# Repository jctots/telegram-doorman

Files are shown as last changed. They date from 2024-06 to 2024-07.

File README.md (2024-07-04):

# 🚪 telegram-doorman
Interact with your [TCS](https://www.tcsag.de/) or [Koch](https://www.kochag.ch/de/) intercom with a Telegram Bot and ESP8266



<table border="0">
<tr><td>Open Door Demo<br></td>
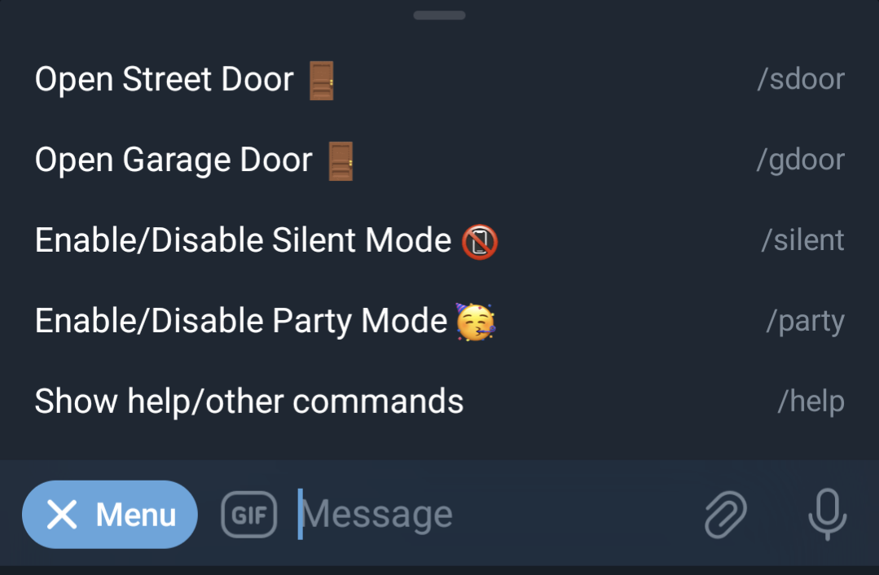
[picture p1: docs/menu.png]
    <td>Telegram Actions<br>
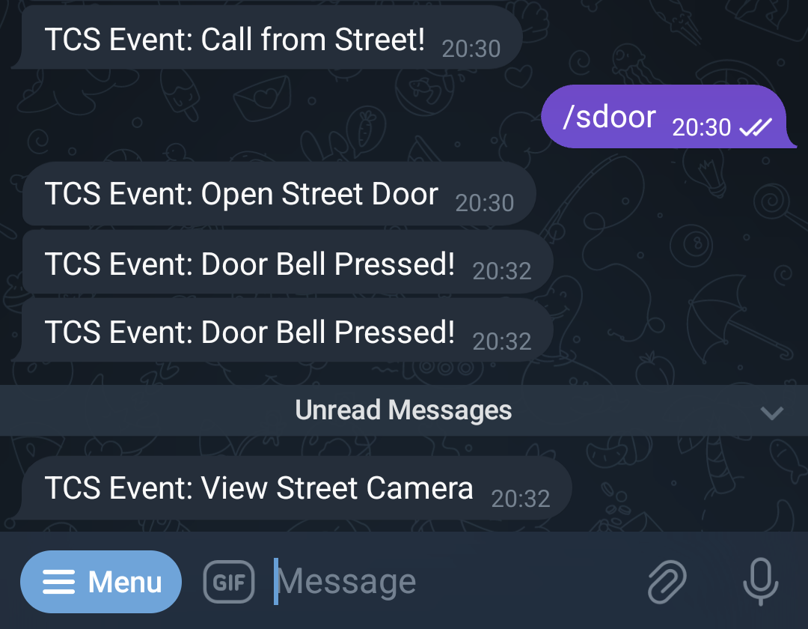
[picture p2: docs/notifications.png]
    <br><br>Example Notifications<br>
    </td>
</tr>
</table>

Currently supported TCS bus events:
- send open door command (up to two doors)
- receive notifications for open door
- receive notifications for intercom call
- receive notifications for apartment doorbell
- receive notifications during lift handset

# 📱 Features
- Multi-user: easily register/remove additional 2 telegram chatIDs (group chatID or user chatID) as bot user
- Silent mode (per user): disable notification of TCS bus events for specific user
- Party mode (all users): automatic door unlock every intercom call
- Sniff mode (main user): forward all TCS bus events (for collecting protocol codes for initial configuration) 
- Dev mode (main user): silent mode for other users and enable sniff mode (useful for debugging and testing)
- Simple DevOps environment via PlatformIO, Arduino OTA, and GitHub Actions

Other hardware-specific features:
- possible isolation of TCS BUS and ESP circuit via optocoupler when ESP is powered by separate supply 
- possible de-isolation of TCS BUS and ESP circuit via jumper when ESP is powered by TCS bus P-Line
- separate pin for resetting config to defaults (short-to-ground)

# ⚙️ System Overview
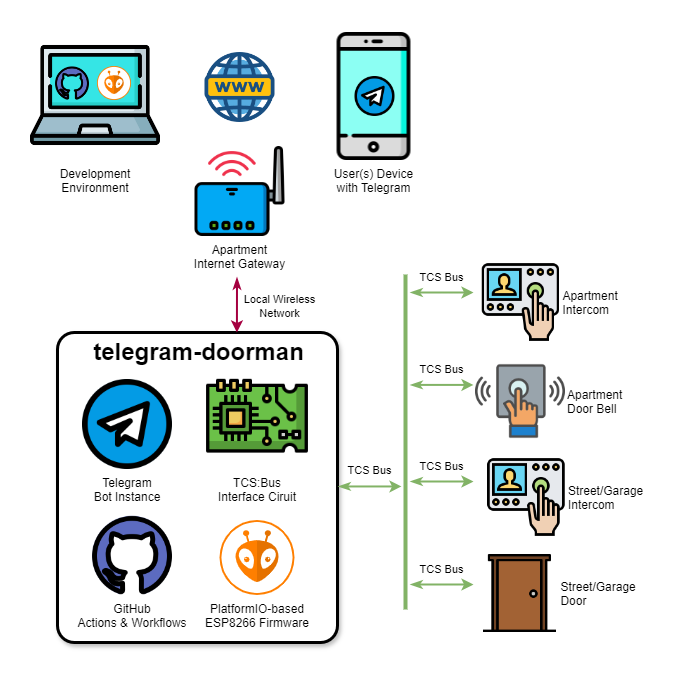
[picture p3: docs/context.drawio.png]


# 🚀 Getting Started
(Detailed user manual coming soon in /docs)
- Setup PlatformIO dev environment and build (or download latest .bin from release)
- Make interface circuit
- Setup Telegram Bot
- Flash, integrate and test
- Enable "Sniff Mode" to capture own TCS:Bus protocol codes
- Change default config with captured codes
- Enjoy!

# 🔧 Reference Circuit and Integration
(Detailed integration manual coming soon in /docs)
<table border="0">
  <tr>
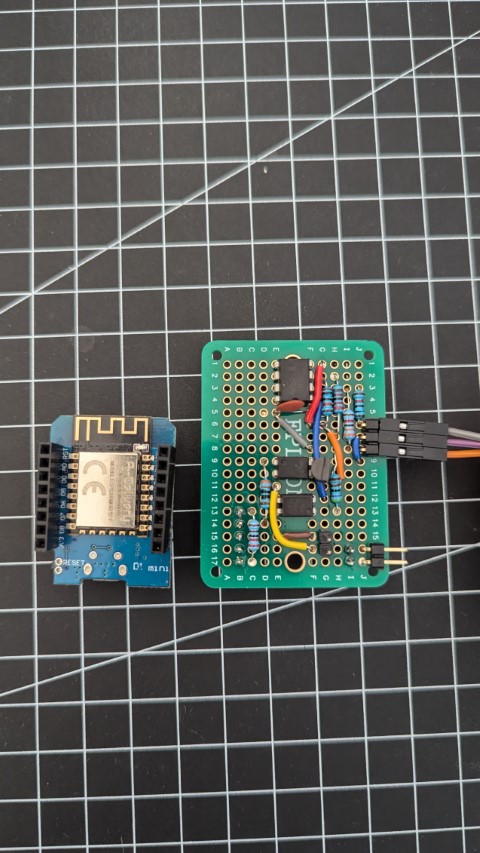
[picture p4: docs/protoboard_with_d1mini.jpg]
    <td></td>
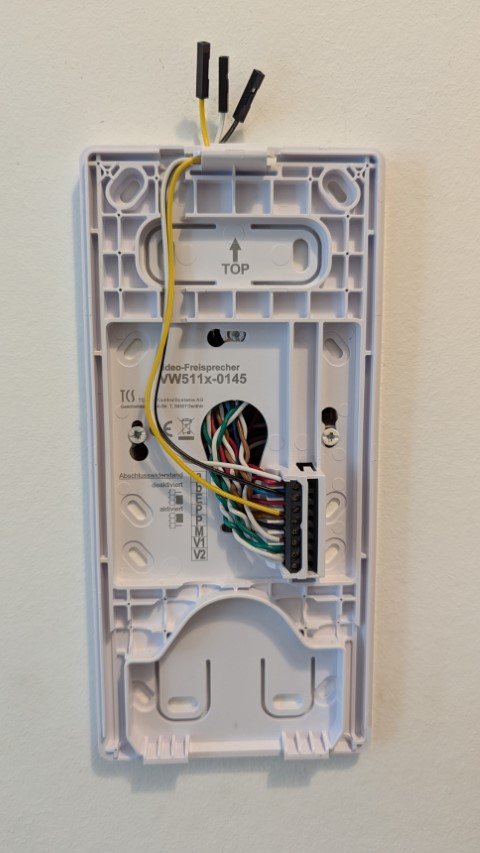
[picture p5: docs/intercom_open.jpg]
    <td></td>
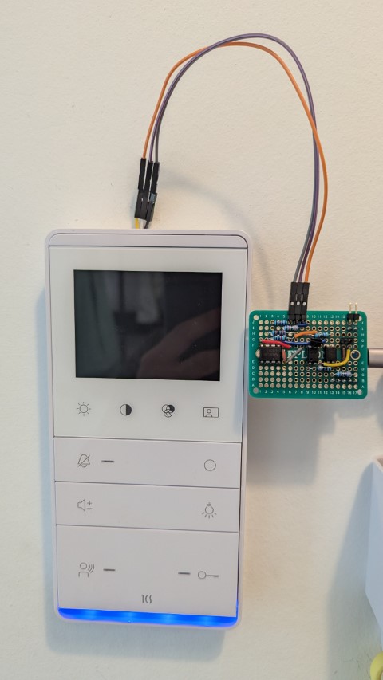
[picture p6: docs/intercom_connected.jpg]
    <td></td>
  </tr>
</table>

[Link to Interface Circuit Schematic Diagram](/docs/schematic.jpg)

# ✔️ To-do 
- [ ] find a way to power ESP from TCS bus P-Line without cracking sound
- [ ] proper cabling and housing
- [ ] support for [telegram-keyman](https://github.com/jctots/telegram-keyman) for complete keyless apartment entry!
- [ ] create user manual, getting started (sphinx-docs), integration manual (with oscilloscope photos)
- [ ] add section for known issues and limitations
- [ ] low power mode/wake-up/proper scheduling for optional battery support
- [ ] PCB layout
- [ ] logs (reset counter, etc.) and error handling
- [ ] simple HTML web server to update config
- [ ] simple web server for wireless serial debugging
- [ ] add sample unit tests for TDD demo
- [ ] create GitHub actions for automated test and docs generation
- [ ] add sample domain and application models for DDD demo

# 🗻 Challenges
- from the [TCS Hacking YouTube video](https://youtu.be/xFLoauqj9yA?si=zF_Vwu4iNptckhIR), the TCS Bus A-Line is between 20V-24V, our system is between 7V-24V (verified using oscilloscope)
- in our apartment, we have 2 doors: main door (facing street) and garage door (inside tiefgarage)
- our system has 6-line TCS bus with video intercom (instead of the usual 2/3 line)
    - getting 5V from the 24V TCS bus P-line using DC-DC buck converter to power the ESP produces noise (cracking sound) in the video intercom (EMI/grounding issues?)
    - decided to use an optocoupler to separate the ESP ground from the TCS bus B-line
 
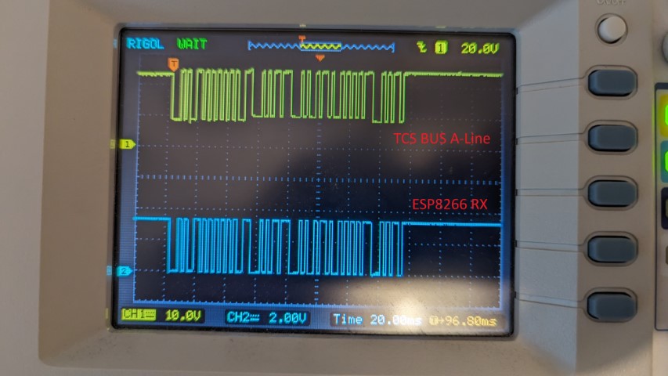
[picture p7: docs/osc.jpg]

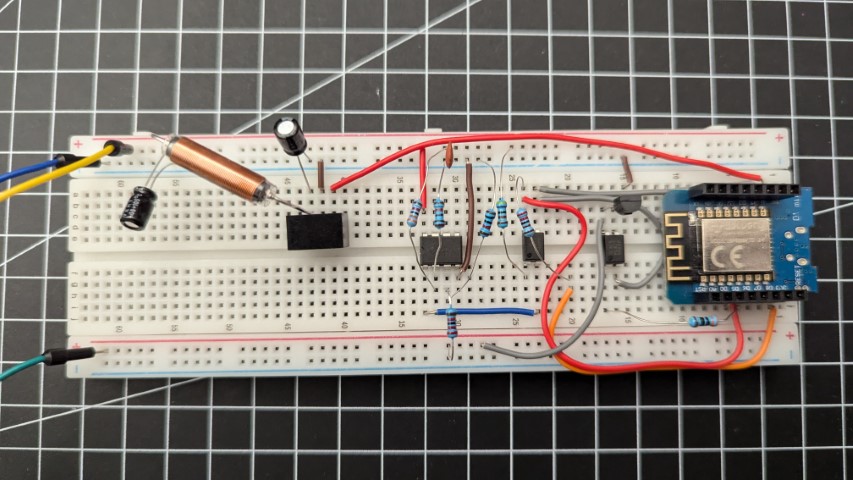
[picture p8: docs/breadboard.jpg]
 

# ✏️ TCS System References 
- [TCS_Systemhandbuch](https://www.tcsag.de/fileadmin/user_upload/TCS_DE/Metanavigation/Downloads/Publikationen/TCS_Systemhandbuch.pdf)
- [PI_IVW511x-0145](https://www.tcsag.de/fileadmin/user_upload/PI_IVW511x-0145.pdf)

# 📜 Credits
- [atc1441's TCSintercomArduino](https://github.com/atc1441/TCSintercomArduino), for the YouTube video and TCS bus decoding
- [peteh's doorman](https://github.com/peteh/doorman), for the TCS bus library
- [AzonInc's Doorman](https://github.com/AzonInc/Doorman), for the insights on ESPhome and home automation
- [witnessmenow's Universal-Arduino-Telegram-Bot](https://github.com/witnessmenow/Universal-Arduino-Telegram-Bot), for the Telegram library
- [Strooom's demoCloudBuilds](https://github.com/Strooom/demoCloudBuilds), for the PlatformIO-baesd CI/CD workflows
- [MrDIYca's wireless-serial-gateway](https://gitlab.com/MrDIYca/wireless-serial-gateway), for insights on serial wifi bridge

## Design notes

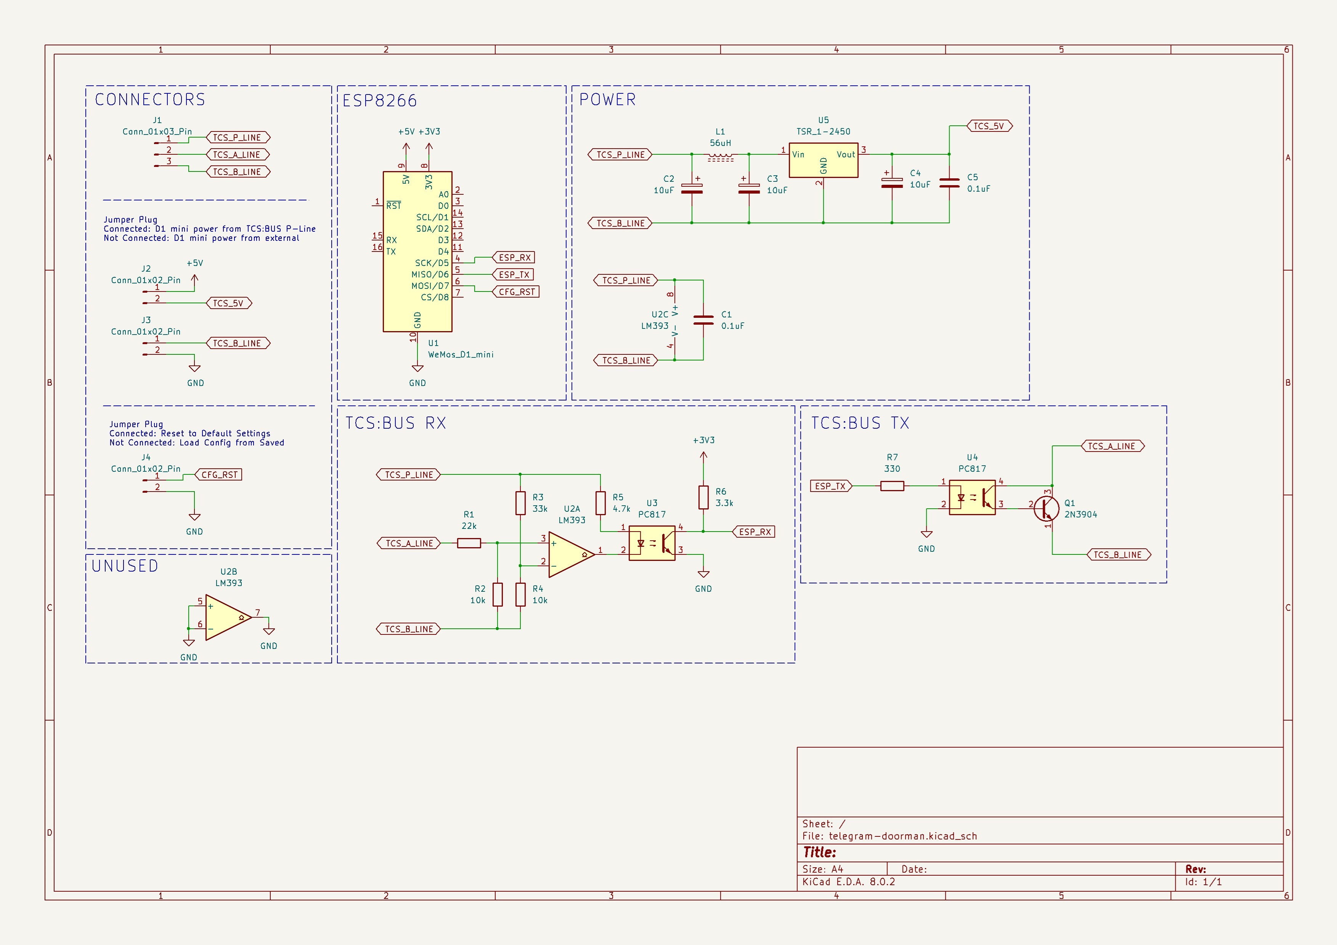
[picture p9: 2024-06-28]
docs/schematic.jpg

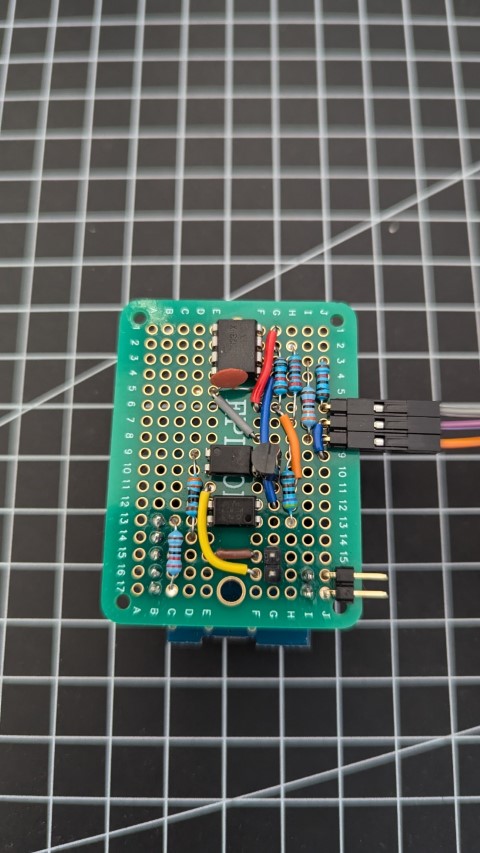
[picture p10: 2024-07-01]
docs/protoboard.jpg

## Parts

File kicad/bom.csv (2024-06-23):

Reference | Value | Datasheet | Footprint | Qty | DNP
C1,C5 | 0.1uF | ~ |  | 2
C2,C3,C4 | 10uF | ~ |  | 3
J1 | Conn_01x03_Pin | ~ |  | 1
J2,J3,J4 | Conn_01x02_Pin | ~ |  | 3
L1 | 56uH | ~ |  | 1
Q1 | 2N3904 | https://www.onsemi.com/pub/Collateral/2N3903-D.PDF | Package_TO_SOT_THT:TO-92_Inline | 1
R1 | 22k | ~ |  | 1
R2,R4 | 10k | ~ |  | 2
R3 | 33k | ~ |  | 1
R5 | 4.7k | ~ |  | 1
R6 | 3.3k | ~ |  | 1
R7 | 330 | ~ |  | 1
U1 | WeMos_D1_mini | https://wiki.wemos.cc/products:d1:d1_mini#documentation | Module:WEMOS_D1_mini_light | 1
U2 | LM393 | http://www.ti.com/lit/ds/symlink/lm393.pdf |  | 1
U3,U4 | PC817 | http://www.soselectronic.cz/a_info/resource/d/pc817.pdf | Package_DIP:DIP-4_W7.62mm | 2
U5 | TSR_1-2450 | http://www.tracopower.com/products/tsr1.pdf | Converter_DCDC:Converter_DCDC_TRACO_TSR-1_THT | 1

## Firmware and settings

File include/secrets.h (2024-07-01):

#pragma once
// Wifi network station credentials
#define DEFAULT_WIFI_SSID "xxxyyyzzz"
#define DEFAULT_WIFI_PASSWORD "xxxyyyzzz"
#define DEFAULT_OTA_PASSWORD "xxxyyyzzz"

// Telegram BOT Token (Get from Botfather)
#define BOT_TOKEN "xxxyyyzzz:xxxyyyzzz"

// Use @myidbot (IDBot) to find out the chat ID of an individual or a group
// Also note that you need to click "start" on a bot before it can
// message you
#define DEFAULT_TELEGRAM_CHAT_ID "xxxyyyzzz"
// for adding/removing new bot users (propose to add '/' at the beginning so bot will not ignore in 'privacy mode')
#define DEFAULT_TELEGRAM_PASSWORD "/xxxyyyzzz"


#define DEFAULT_TCS_APT_BELL 0xDEADBEEF
#define DEFAULT_TCS_STREET_CALL 0xDEADBEEF
#define DEFAULT_TCS_GARAGE_CALL 0xDEADBEEF
#define DEFAULT_TCS_STREET_VIEW 0xDEADBEEF
#define DEFAULT_TCS_GARAGE_VIEW 0xDEADBEEF
#define DEFAULT_TCS_STREET_OPEN 0xDEADBEEF
#define DEFAULT_TCS_GARAGE_OPEN 0xDEADBEEF

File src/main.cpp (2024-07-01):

#include <ESP8266WiFi.h>
#include <WiFiClientSecure.h>
#include <UniversalTelegramBot.h>
#include <ArduinoJson.h>
#include <LittleFS.h>
#include <ArduinoOTA.h>

#include <TCSBus.h>
#include <SimpleTimer.h>

#include "platform.h"
#include "secrets.h"
#include "dataHandler.h"
#include "eventHandler.h"

const unsigned long BOT_MTBS = 1000; // mean time between scan messages
unsigned long bot_lasttime;          // last time messages' scan has been done


Config config = {
  {DEFAULT_WIFI_SSID, DEFAULT_WIFI_PASSWORD, DEFAULT_OTA_PASSWORD},
  {DEFAULT_TELEGRAM_CHAT_ID, "0", "0", DEFAULT_TELEGRAM_PASSWORD},
  {DEFAULT_TCS_APT_BELL, DEFAULT_TCS_STREET_CALL, DEFAULT_TCS_GARAGE_CALL, DEFAULT_TCS_STREET_VIEW, DEFAULT_TCS_GARAGE_VIEW, DEFAULT_TCS_STREET_OPEN, DEFAULT_TCS_GARAGE_OPEN},
  0,  0,  0,  0,  0,  0,  0,  0,  0,  0,
};


X509List cert(TELEGRAM_CERTIFICATE_ROOT);
WiFiClientSecure secured_client;
UniversalTelegramBot bot(BOT_TOKEN, secured_client);

TCSBusReader tcsReader(PIN_BUS_READ);
TCSBusWriter tcsWriter(PIN_BUS_WRITE);

SimpleTimer timerLedPeriod(3000, &LedPeriodTimeout); // every 3 seconds
SimpleTimer timerLedPulse(10, &LedPulseTimeout);    // turn ON LED for 10ms

String chat_id = "0";
String text = "0";
String from_name = "0";

String chat_id_new_user = "0";

void setup(void)
{

  //initialize LED for busy status
  pinMode(LED_BUILTIN, OUTPUT);
  digitalWrite(LED_BUILTIN, LOW); // turn on LED busy status

  //initialize serial for debugging purposes
  Serial.begin(115200);
  Serial.println();
  Serial.println("\n\n\n-- setup start --");

  //setup and load config
  setupConfig();

  // attempt to connect to Wifi network:
  Serial.print("Connecting to Wifi SSID ");
  Serial.print(config.wifi.ssid);
  WiFi.begin(config.wifi.ssid, config.wifi.password);
  secured_client.setTrustAnchors(&cert); // Add root certificate for api.telegram.org
  while (WiFi.status() != WL_CONNECTED)
  {
    Serial.print(".");
    delay(500);
  }
  Serial.print("\nWiFi connected. IP address: ");
  Serial.println(WiFi.localIP());

  Serial.print("Retrieving time: ");
  configTime(0, 0, "pool.ntp.org"); // get UTC time via NTP
  time_t now = time(nullptr);
  while (now < 24 * 3600)
  {
    Serial.print(".");
    delay(100);
    now = time(nullptr);
  }
  Serial.println(now);

  //alive
  sendTelegramBroadcast("[Bot Event] Startup");
  chat_id = config.telegram.chatId0;
  handleStatusRequest();

  //initialize TCS 
  tcsReader.begin();
  tcsWriter.begin();

  //initialize heartbeat timers
  timerLedPeriod.stop();
  timerLedPulse.stop();

  //initialize OTA
  // Port defaults to 8266
  ArduinoOTA.setPort(8266);
  // Hostname defaults to esp8266-[ChipID]
  ArduinoOTA.setHostname("telegram-doorman");
  // No authentication by default
  ArduinoOTA.setPassword(DEFAULT_OTA_PASSWORD);
  
  ArduinoOTA.onStart([]() {
    String type;
    if (ArduinoOTA.getCommand() == U_FLASH) {
      type = "sketch";
    } else {  // U_FS
      type = "filesystem";
    }

    // NOTE: if updating FS this would be the place to unmount FS using FS.end()
    Serial.println("Start updating " + type);
  });
  ArduinoOTA.onEnd([]() {
    Serial.println("\nEnd");
  });
  ArduinoOTA.onProgress([](unsigned int progress, unsigned int total) {
    Serial.printf("Progress: %u%%\r", (progress / (total / 100)));
  });
  ArduinoOTA.onError([](ota_error_t error) {
    Serial.printf("Error[%u]: ", error);
    if (error == OTA_AUTH_ERROR) {
      Serial.println("Auth Failed");
    } else if (error == OTA_BEGIN_ERROR) {
      Serial.println("Begin Failed");
    } else if (error == OTA_CONNECT_ERROR) {
      Serial.println("Connect Failed");
    } else if (error == OTA_RECEIVE_ERROR) {
      Serial.println("Receive Failed");
    } else if (error == OTA_END_ERROR) {
      Serial.println("End Failed");
    }
  });
  ArduinoOTA.begin();

  Serial.println("-- setup end --\n\n\n");

  //start heartbeat
  timerLedPeriod.start();

  //turn off LED busy status
  digitalWrite(LED_BUILTIN, HIGH); 
}










void loop() {
  //part 1: handle OTA
  ArduinoOTA.handle();

  //part 2: handle TCS bus event
  if (tcsReader.hasCommand()) {
    uint32_t cmd = tcsReader.read();
    
    // loop event check
    for (uint8_t n=0; n<N_TCS_EVENTS; n++) {
      if (cmd == TcsEvents[n].cmd) {
        TcsEvents[n].event();
        break;
      }
    }
    
    if (config.sniffMode == true) handleSniffMode(cmd);
    else;
  }

  //part 3: handle telegram updates
  if (millis() - bot_lasttime > BOT_MTBS)
  {
    int numNewMessages = bot.getUpdates(bot.last_message_received + 1);

    while (numNewMessages)
    {
      for (int i = 0; i < numNewMessages; i++)
      {
        chat_id = bot.messages[i].chat_id;
        text = bot.messages[i].text;
        from_name = bot.messages[i].from_name;
    
        // debug
        String debug_msg = "Chat id: " + chat_id + "\tFrom: " + from_name + "\tText: " + text;
        Serial.println(debug_msg);

        // respond only if registered user
        if ((strcmp(config.telegram.chatId0, chat_id.c_str()) == 0) ||
            (strcmp(config.telegram.chatId1, chat_id.c_str()) == 0) ||
            (strcmp(config.telegram.chatId2, chat_id.c_str()) == 0)) 
        {
          // loop event check
          for (uint8_t n=0; n<N_BOT_EVENTS; n++) {
            if (text == BotEvents[n].text) {
              BotEvents[n].event();
              break;
            }
            // break did not hit
            else if (n == N_BOT_EVENTS-1) handleUnknownRequest();
          }
        }
        // if unknown user, but want to register
        else if (text == "/start") handleStartRequest();
        // unknown user enters password
        else if (chat_id_new_user == chat_id) handlePasswordCheck();
        // if unknown user, and unknown command
        else; // no response
      }
      numNewMessages = bot.getUpdates(bot.last_message_received + 1);
    }
    bot_lasttime = millis();
  }

  //part 4: handle heartbeat
  timerLedPeriod.check();
  timerLedPulse.check();

}

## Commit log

2024-06-23 hello world
    [bom.csv, telegram-doorman.kicad_pcb, telegram-doorman.kicad_sch]
2024-06-23 remove and ignore kicad backups
2024-06-23 added osc and circuit photos
2024-06-28 add ota, fix door open notif,
    [telegram-doorman.kicad_sch]
